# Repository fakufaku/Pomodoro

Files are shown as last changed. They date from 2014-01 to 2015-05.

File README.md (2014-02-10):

Pomodoro
========

A custom built timer for the [pomodoro technique](http://pomodorotechnique.com/).

Use it
------

1. One click starts a 25 minutes _work_ counter. Five yellow LED indicates how
  many slices of five minutes are left. There is a discrete beep when the timer
  expires. The LED then flashes to remind you to go into _rest_ mode.
2. A second click starts a 5 minutes _rest_ counter. A **red** LED is turned on.
  There is a discrete beep when it expires. Then the timer turns off.
3. If you wish the turn the timer off during _rest_ mode, click a third time the button.

Build it
--------

### Bill Of Material

* 1x ATtiny85
* 5x LED yellow, SMD 0805
* 1x LED red, SMD 0805
* 3x 22 Ohm Resistor, SMD 0805
* 2x 1K Ohm Resistor, SMD 0805
* 1x NPN BJT transistor, SOT-23 (BC846CMTF)
* 1x 1mH Inductor, SMD 1007
* 1x Buzzer, SMD [mouser](http://www.mouser.com/ProductDetail/Kobitone/254-PB501-ROX/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)
* 1x CR2032 coin cell holder, SMD [mouser](http://www.mouser.com/ProductDetail/Linx-Technologies/BAT-HLD-001/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)
* 1x Tactile switch, SMD EVQ-Q2 [mouser](http://www.mouser.com/ProductDetail/Panasonic/EVQ-Q2K03W/?qs=sGAEpiMZZMsgGjVA3toVBA4puZS2llK5hCEf4xZ%2f9rI%3d)

### Schematic

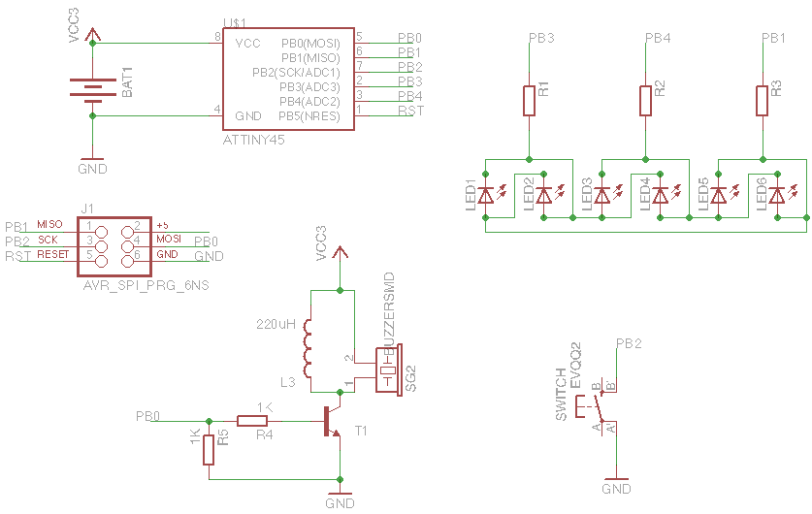
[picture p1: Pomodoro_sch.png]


### Etch the PCB

The PCB can be etched using the [mask](Pomodoro_mask.eps) provided in EPS format.
Here is a picture of the layout.

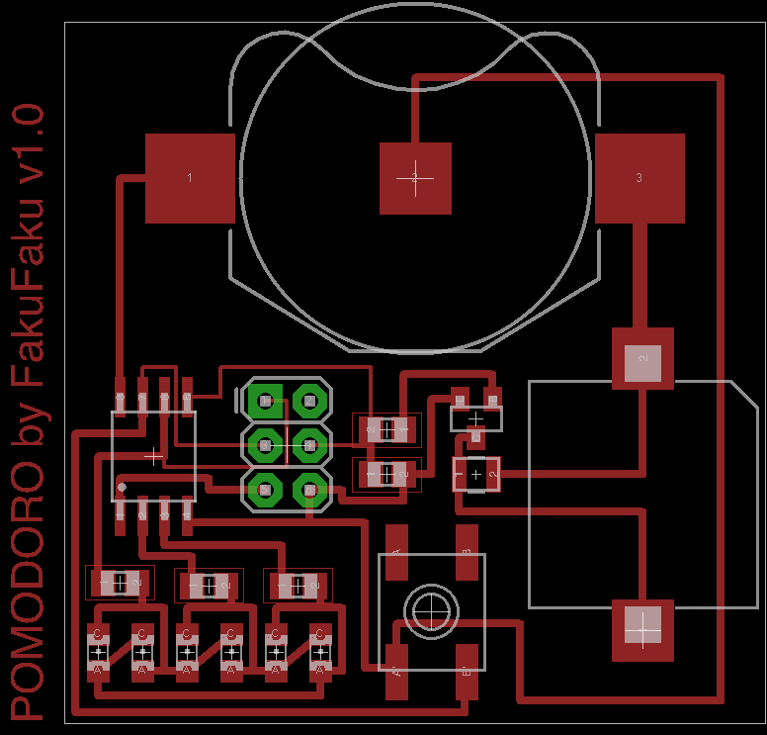
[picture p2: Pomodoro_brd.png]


### Firmware

The firmware is in the `firmware` folder. It can be uploaded using avrdude and
a [usbtiny-isp](https://www.sparkfun.com/products/9825), for example. The idea is
to press a six-pin header againt the PCB directly when programing. Some spring-loaded
pins would be ideal for the job. The square pad is pad number one of a six-pin ISP
header.

To compile and upload (assuming you have avr-gcc and avrdude installed), type the
following in a terminal.

    make avrdude

The Code
--------

My goal was to use explore the possibilities of the ATtiny85 microcontroller. We use it here
as a timer that first counts 25 minutes (work time) and emit a signal. Then, we can start a second
counter for 5 minutes (rest time). Here is what we use.

* A tactile switch connected to the _INT0_ of the avr as the sole user input. We use it
  to turn the counter off and switch between different modes.
* A buzzer to give a discrete signal when the timer expires. The buzzer is driven
    by _TIMER0_ in PWM mode at 4 kHz, 50% duty cycle.
* As many LEDs as possible to indicate the progress of the timer. By default,
    the ATtiny85 has 5 GPIO pins (we could add an extra one, but would lose ISP).
    We have thus 3 GPIO remaining.   
    We assign all of them to LEDs and using
    [charlieplexing](https://en.wikipedia.org/wiki/Charlieplexing), it is
    possible to drive 6 LEDs using only 3 pins. We choose 5 yellow, for every 5
    minutes slice of the first timer, and a single red one, for the _rest time_
    of the second timer.

The code is completely interrupt driven. _TIMER1_ and its overflow interrupt
are used to keep track of time during each state. The tactile switch triggers
an interrupt to wake up the avr, or switch between states. The [finite state
machine](https://en.wikipedia.org/wiki/Finite-state_machine) looks like this.
Blue arrows are state switching triggered by a push on the button. Red arrows
are switching caused by the timer expiration.

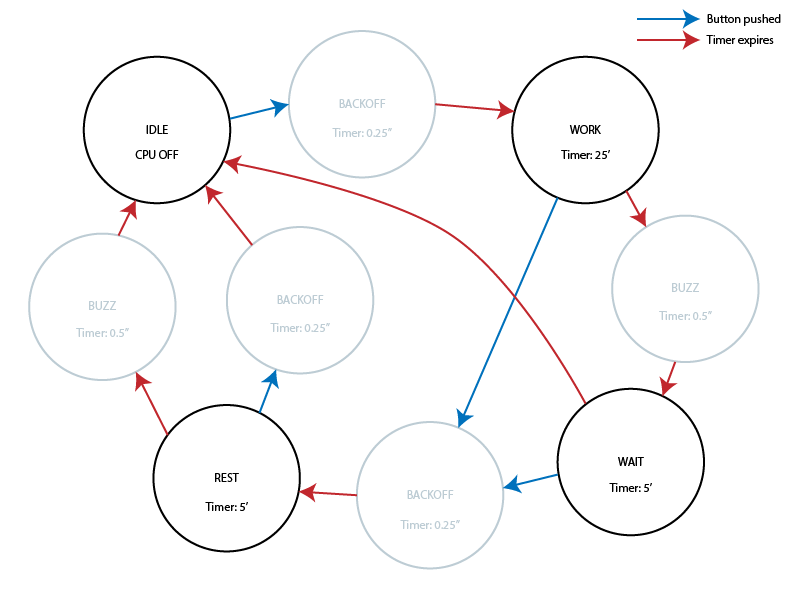
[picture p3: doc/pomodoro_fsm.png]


The _main_ states are black circles. The grey circles are the transition states.
It was important to add the `BACKOFF` state to debounce the tactile button because it triggered multiple interrupts.

License
-------

2014 (c) Robin Scheibler aka FakuFaku

    "THE BEER-WARE LICENSE" (Revision 42):
    <fakufaku@gmail.com> wrote this file. As long as you retain this notice you
    can do whatever you want with this stuff. If we meet some day, and you think
    this stuff is worth it, you can buy me a beer in return -- Robin Scheibler



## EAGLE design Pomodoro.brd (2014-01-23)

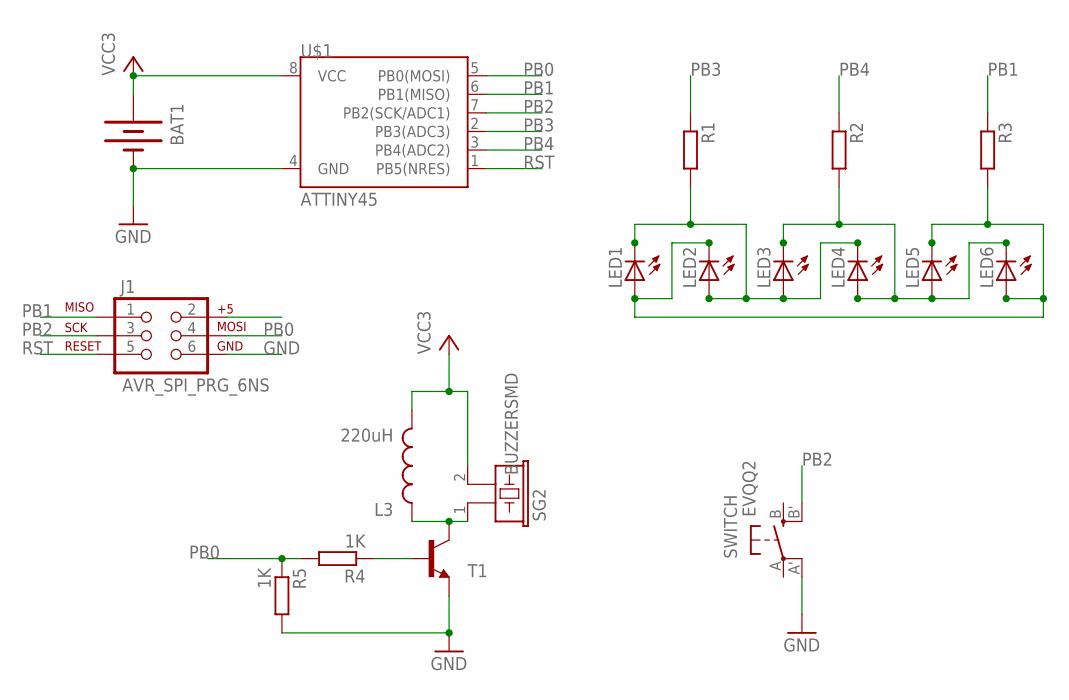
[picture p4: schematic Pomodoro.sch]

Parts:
BAT1: BATTERY20SMD; BATTCON_20MM
J1: AVR_SPI_PRG_6NS; 2X3-NS
L3: 220uH; 1007
LED1, LED2, LED3, LED4, LED5, LED6: LEDCHIPLED_0805; CHIPLED_0805
R1, R2, R3: R-EU_R0805; R0805
R4, R5: 1K; R0805
SG2: BUZZERSMD; KOBITONE-254-PB501-ROX
SWITCH: EVQQ2; EVQ-Q2
T1: BC849-NPN-SOT23-BEC; SOT23-BEC
U$1: ATTINY45; SO08-EIAJ

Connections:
GND: BAT1.2 (-), J1.6, R5.2, SWITCH.A' (P1), T1.E, U$1.4 (GND)
unnamed: R4.1, T1.B
unnamed: LED1.C, LED2.A, LED3.A, LED4.C, R1.2
unnamed: L3.1, SG2.1, T1.C
unnamed: LED3.C, LED4.A, LED5.A, LED6.C, R2.2
unnamed: LED1.A, LED2.C, LED5.C, LED6.A, R3.2
PB0: J1.4, R4.2, R5.1, U$1.5 (PB0(MOSI))
PB1: J1.1, R3.1, U$1.6 (PB1(MISO))
PB2: J1.3, SWITCH.B' (S1), U$1.7 (PB2(SCK/ADC1))
PB3: R1.1, U$1.2 (PB3(ADC3))
PB4: R2.1, U$1.3 (PB4(ADC2))
RST: J1.5, U$1.1 (PB5(NRES))
VCC3: BAT1.1 (+), BAT1.3 (+), L3.2, SG2.2, U$1.8 (VCC)

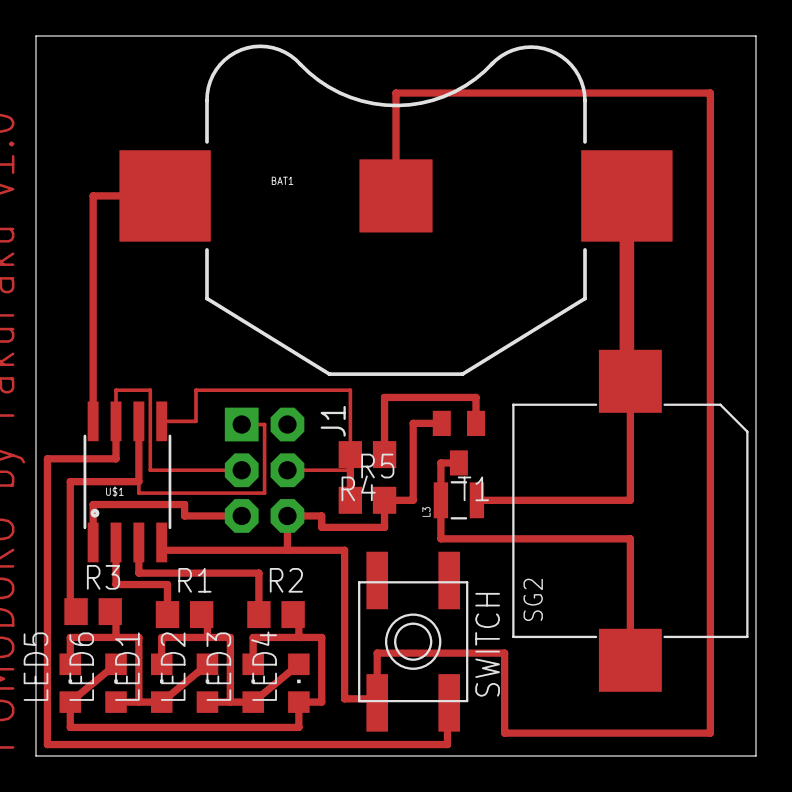
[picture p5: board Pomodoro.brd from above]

Board: 2 copper layers, 40.0 x 40.0 mm, 18 parts (0 on the bottom side), 13 nets.

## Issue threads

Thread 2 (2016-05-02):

SMD Buzzer no longer available

mihow, 2016-05-02:
It looks like the Kobitone 254-PB501-ROX buzzer is no longer available on Mouser. Is there an alternative part that fits the same footprint on the PCB?

http://www.mouser.com/ProductDetail/Kobitone/254-PB501-ROX

mihow, 2016-05-02:
These 2 look like candidates. Both have the solder tabs that stick out and the dimensions seem close enough to fit on the current PCB pads. Hard to tell if they if they are externally driven though.

http://www.mouser.com/ProductDetail/PUI-Audio/SMT-1341-T-2-R
http://www.mouser.com/ProductDetail/Kobitone/254-PB119-ROX

fakufaku, 2016-05-06:
Hi @mihow , thanks for letting me know. I have not checked other parts yet, but it looks like the Kobitone PB119 you suggest might be suitable. According to the datasheet it is externally driven. It is slightly smaller than the PB501 but it seems the lead should stick out about 1.5 mm onto the pads, enough to solder them.
Let me know if it works or if you find something better.

Alexisgm7, 2020-07-15:
Hello!

I am sorry to write this here but I don't really know how Github works yet as I am starting to use it.

I really lile your pomodoro timer and I would like to make it. Howevee, as I am learning how to code, I only know how to upload code to Attiny with Arduino as ISP. Is it possible to convert the .c file to arduino? If so, do you have such file?

If it is not possible, could you explain me or recommend me a web where how to upload codes with an usb-isp is explained properly? I can't seem to find any useful page.

Thank you very much.

Alexis.

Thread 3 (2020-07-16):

Uploading the firmware to device

fakufaku, 2020-07-16:
Hello!

I am sorry to write this here but I don't really know how Github works yet as I am starting to use it.

I really lile your pomodoro timer and I would like to make it. Howevee, as I am learning how to code, I only know how to upload code to Attiny with Arduino as ISP. Is it possible to convert the .c file to arduino? If so, do you have such file?

If it is not possible, could you explain me or recommend me a web where how to upload codes with an usb-isp is explained properly? I can't seem to find any useful page.

Thank you very much.

Alexis.

_Originally posted by @Alexisgm7 in https://github.com/fakufaku/Pomodoro/issues/2#issuecomment-658940123_

fakufaku, 2020-07-16:
Hi @alexisgm7, I have opened a new issue about this.

You can use [avrdude](https://www.nongnu.org/avrdude/). There is a very complete tutorial [here](https://www.ladyada.net/learn/avr/) including how to install it on various platforms.

Once you have installed avrdude, you can use the Makefile in `firmware` folder to upload to compile and upload to device.
```bash
cd ./firmware
make avrdude
```
You might have to edit the top of the Makefile to indicate the type of ISP (`PROGRAMMER`) and the USB port (`PORT`) you are using
```Makefile
CC=avr-gcc
PROGRAMMER=avrisp2
PORT=usb
CPU=attiny85
```

Hope this helps.

Alexisgm7, 2020-07-16:
Thank you very much for all the help. Now I have to put my hand on it and start working and making the pcb.

If I have any question I will ask you!!

Thanks.

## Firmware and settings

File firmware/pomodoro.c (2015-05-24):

/*
* ----------------------------------------------------------------------------
* "THE BEER-WARE LICENSE" (Revision 42):
* <fakufaku@gmail.com> wrote this file. As long as you retain this notice you
* can do whatever you want with this stuff. If we meet some day, and you think
* this stuff is worth it, you can buy me a beer in return -- Robin Scheibler
* ----------------------------------------------------------------------------
*/

#include <avr/sleep.h>
#include <avr/io.h>
#include <avr/interrupt.h>

// Allows to disable interrupt in some parts of the code
#define ENTER_CRIT()    {char volatile saved_sreg = SREG; cli()
#define LEAVE_CRIT()    SREG = saved_sreg;}

// We assume 1MHz CPU clock divided by 16384
#define FIVE_MINUTES 72

// OVF period is ~4.2s
#define TIMER1_CLKDIV16384 ((1 << CS13) | (1 << CS12) | (1 << CS11) | (1 << CS10))
// OVF period is ~1.05s
#define TIMER1_CLKDIV4096  ((1 << CS13) | (1 << CS12) | (1 << CS10))
// OVF period is ~0.26s
#define TIMER1_CLKDIV1024  ((1 << CS13) | (1 << CS11) | (1 << CS10))
// OVF period is ~0.13s
#define TIMER1_CLKDIV512   ((1 << CS13) | (1 << CS11))
// disable TIMER1
#define TIMER1_DISABLED 0
// macro to set timer1
#define SET_TIMER1(x) {TCCR1 = x; TCNT1 = 0x0;}

// beginning of work 
unsigned long timer_counter = 0;

// LED on/off array
unsigned char LED_array = 0;

// the state variable
#define IDLE 0
#define WORK 1
#define BUZZ 2
#define WAIT 3
#define REST 4
#define BKOF 5
unsigned char state = IDLE;
unsigned char next_state = IDLE;

void set_state(int new_state)
{
  switch (new_state)
  {
    case WORK:
      // go into WORK time
      state = WORK;
      timer_counter = 5*FIVE_MINUTES-1;
      SET_TIMER1(TIMER1_CLKDIV16384);
      LED_array = 0x1F;
      break;

    case REST:
      // go into REST time
      state = REST;
      timer_counter = FIVE_MINUTES-1;
      SET_TIMER1(TIMER1_CLKDIV16384);
      LED_array = 0x20;
      break;

    case IDLE:
      // go back to IDLE mod
      state = IDLE;
      SET_TIMER1(TIMER1_DISABLED);
      LED_array = 0x00;
      break;

    case BUZZ:
      state = BUZZ;
      timer_counter = 3;
      SET_TIMER1(TIMER1_CLKDIV512);
      LED_array = 0x00;
      break;

    case WAIT:
      // go to WAIT state
      state = WAIT;
      timer_counter = FIVE_MINUTES-1;
      LED_array = 0x1F;
      SET_TIMER1(TIMER1_CLKDIV16384);
      break;

    case BKOF:
      // go to backoff state (debounce button)
      state = BKOF;
      SET_TIMER1(TIMER1_CLKDIV1024);
      LED_array = 0x0;
      break;
  }
}

// macros to access individual LEDs through Charlieplexing
void led_on(int p)
{
  switch (p)
  {
    case 2: // LED1
      DDRB |= (1 << DDB3);
      DDRB |= (1 << DDB1);
      DDRB &= ~(1 << DDB4);

      PORTB &= ~(1 << 3);
      PORTB &= ~(1 << 4);
      PORTB |= (1 << 1);

      break;

    case 3: // LED2
      DDRB |= (1 << DDB3);
      DDRB |= (1 << DDB1);
      DDRB &= ~(1 << DDB4);

      PORTB &= ~(1 << 1);
      PORTB &= ~(1 << 4);
      PORTB |= (1 << 3);

      break;

    case 4: // LED3
      DDRB |= (1 << DDB3);
      DDRB |= (1 << DDB4);
      DDRB &= ~(1 << DDB1);

      PORTB &= ~(1 << 1);
      PORTB &= ~(1 << 4);
      PORTB |= (1 << 3);

      break;

    case 5: // LED4
      DDRB |= (1 << DDB3);
      DDRB |= (1 << DDB4);
      DDRB &= ~(1 << DDB1);

      PORTB &= ~(1 << 1);
      PORTB &= ~(1 << 3);
      PORTB |= (1 << 4);

      break;

    case 0: // LED5
      DDRB |= (1 << DDB1);
      DDRB |= (1 << DDB4);
      DDRB &= ~(1 << DDB3);

      PORTB &= ~(1 << 3);
      PORTB &= ~(1 << 1);
      PORTB |= (1 << 4);

      break;

    case 1: // LED6
      DDRB |= (1 << DDB1);
      DDRB |= (1 << DDB4);
      DDRB &= ~(1 << DDB3);

      PORTB &= ~(1 << 3);
      PORTB &= ~(1 << 4);
      PORTB |= (1 << 1);

      break;

    default:
      // turn all LEDs off
      DDRB &= ~(1 << DDB1) & ~(1 << DDB3) & ~(1 << DDB4);
      PORTB &= ~(1 << 1) & ~(1 << 3) & ~(1 << 4);;
      break;
  }
}

// the start and stop buzz functions
void buzz_start()
{
  // set PB0 as output
  DDRB |= (1 << DDB0);

  // Fast PWM, OC0A, non-inverting
  // no clock divider (~4kHz @ clk 1MHz)
  TCCR0A = (1 << COM0A1) | (1 << WGM01) | (1 << WGM00);
  TCCR0B = (1 << CS00);
  OCR0A = 128;  // half duty cycle
}

void buzz_stop()
{
  TCCR0A = 0x0;   // stop timer
  DDRB &= ~(1 << DDB0); // set PB0 as input
}

// The timer overflow interrupt routine
SIGNAL(TIMER1_OVF_vect)
{
  ENTER_CRIT();

  switch(state)
  {
    case WORK:
      if (timer_counter > 0)
      {
        // This will light one LED for each 5 second slice remaining
        LED_array = ((1 << 5)-1) ^ (1 << (((5*FIVE_MINUTES)-timer_counter)/FIVE_MINUTES))-1;
        timer_counter--;
      }
      else
      {
        set_state(BUZZ);
        next_state = WAIT;
      }
      break;

    case WAIT:
      // in this state, we just blink yellow/red LEDs alternatively
      if (timer_counter == 0)
      {
        // if the timer expire without any action, turn off
        set_state(IDLE);
      }
      else if (timer_counter % 2 == 0)
      {
        // red
        LED_array = 0x20;
        timer_counter--;
      }
      else
      {
        // yellow
        LED_array = 0x1F;
        timer_counter--;
      }
      break;

    case REST:
      if (timer_counter > 0)
      {
        LED_array = (1 << 5);
        timer_counter--;
      }
      else
      {
        set_state(BUZZ);
        next_state = IDLE;
      }
      break;
      
    case BUZZ:
      // control buzzer
      if (timer_counter % 2 == 1)
        buzz_start();
      else
        buzz_stop();
      // control time
      if (timer_counter > 0)
      {
        timer_counter--;
      }
      else
      {
        set_state(next_state);
      }
      break;

    case BKOF:
      set_state(next_state);
      break;

  }

  LEAVE_CRIT();
}

// The button interrupt routine
SIGNAL(INT0_vect)
{
  // go into safe mode
  ENTER_CRIT();

  // state machine
  switch (state)
  {
    case IDLE:
      set_state(BKOF); // debounce
      // go into WORK time
      next_state = WORK;
      break;

    case BKOF:
    case BUZZ:
      break;

    case WORK:
    case WAIT:
      set_state(BKOF); // debounce
      // go into rest mode
      next_state = REST;
      break;

    case REST:
      set_state(BKOF); // debounce
      // go back to IDLE mod
      next_state = IDLE;
      break;
  }
  
  // leave safe mode
  LEAVE_CRIT();
}

// prepare and go to sleep.
void go_to_sleep()
{
  // turn off all LEDs
  LED_array = 0;

  // Turn all ports into inputs and disable pull-ups (except for interrupt)
  DDRB &= ~(1 << DDB0) & ~(1 << DDB1) & ~(1 << DDB3) & ~(1 << DDB4);
  PORTB &= ~(1 << 0) & ~(1 << 1) & ~(1 << 3) & ~(1 << 4);

  // The CPU can only wake up from power down through a LOW-LEVEL interrupt
  MCUCR &= ~(1 << ISC01) & ~(1 << ISC00); // INT0 interrupt on low level
 
  // Power reduction (shut down both timers, USI and ADC)
  PRR = (1 << PRUSI) | (1 << PRADC);

  // Disable watchdog completely
  WDTCR = 0x0;

  /* put the cpu in deepest sleep mode */
  set_sleep_mode(SLEEP_MODE_PWR_DOWN);
  sleep_enable();
  sleep_cpu();
  sleep_disable();
  
  // In normal use, we want the button interrupt to happen on falling edge.
  MCUCR |= (1 << ISC01);

}

int main()
{
  int i;

  // enable interrupts
  sei();

  // setup button on PB2 
  DDRB &= ~(1 << DDB2);
  PORTB |= (1 << 2);     // enable pull-up
  MCUCR |= (1 << ISC01); // interrupt on falling edge
  GIMSK |= (1 << INT0);  // enable interrupt 0
 

  // set up timer 1 as system clock
  TCCR1 = (1 << CS13) | (1 << CS12) | (1 << CS10); // T1 clock to clk/4096
  TIMSK = (1 << TOIE1);   // set the overflow interrupt

  // The infinite loop
  while (1)
  {
    // turn off if IDLE
    if (state == IDLE)
      go_to_sleep();

    // display LEDs
    for (i = 0 ; i < 6 ; i++)
    {
      if ((LED_array >> i) & 1)
        led_on(i);
      else
        led_on(-1);
    }

    if (LED_array == 0x0)
      led_on(-1);
      
  }

}

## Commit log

2014-01-23 Adding png images of schematics and board. README. gitignore. mask.
2014-01-23 Added license in code.
    [Pomodoro.brd]
2014-02-03 Added debounce for tactile switch. Cleaned state machine.
2014-02-10 Edit BOM to reflect transistor T1
    According to the datasheet for the BC846CMTF and the schematic,
    In the BOM located in README.md, the line
    1x PNP BPJ transistor, SOT-23 (BC846CMTF)
    should state
    1x NPN BJT transistor, SOT-23 (BC846CMTF)
